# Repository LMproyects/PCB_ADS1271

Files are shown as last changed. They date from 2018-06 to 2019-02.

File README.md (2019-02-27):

# Diseño PCB de prueba para ADS1271

## Diseñadores
* Luciano Villarreal
* Marcos Postemsky

## Elección de pines

## Modo de operación
Vamos a trabajar con comunicación SPI, adquiriendo datos de forma continua (SYNC-PDWN='1')

## Pines a PinMod

**Para trabajar con SPI**
* **CLK:** reloj continuo que utiliza el ADC para muestreo y conversión.
* **SCLK:** Reloj utilizado para la comunicación SPI.
* **DOUT:** Datos de salida SPI.
* **DRDY:** Una vez que los datos válidos están listos, DRDY se pone en bajo.

### Pines ADS1271 fijos
* **SYNC/PDWN:** Se mantiene este valor en alto, para poder trabajar con adquisición de datos de manera continua. 

## Componentes necesarios
- 1 ADS1271: ADC de 24 bits Delta&Sigma con entrada y referencia diferencial.
- 6 pines con curva de 90º.
- 1 LM7805
- 1 Capacitor electrolítico 0.33 uF, 25V.
- 2 Capacitores electrolítico 0.1 uF
- 2 Capacitores electrolítico 10 uF
- 2 Capacitores cerámica 100 pF
- 1 Capacitores cerámica 1 nF
- 5 Resistencias de 50 Ohmios
- 1 Resistencia de 680 Ohmios
- 1 LM336z2.5 (se puede cambiar por zener de 2.5 v)
- 2 pines 2.54 mm
- 2 pines 2.54 mm

## Diseño del esquematico
Para el diseño del esquemático que será utilizado en el PCB de prueba, se tiene en cuenta el circuito recomendado por el fabricante Texas Instruments. A continuación, puede verse el circuito mencionado.

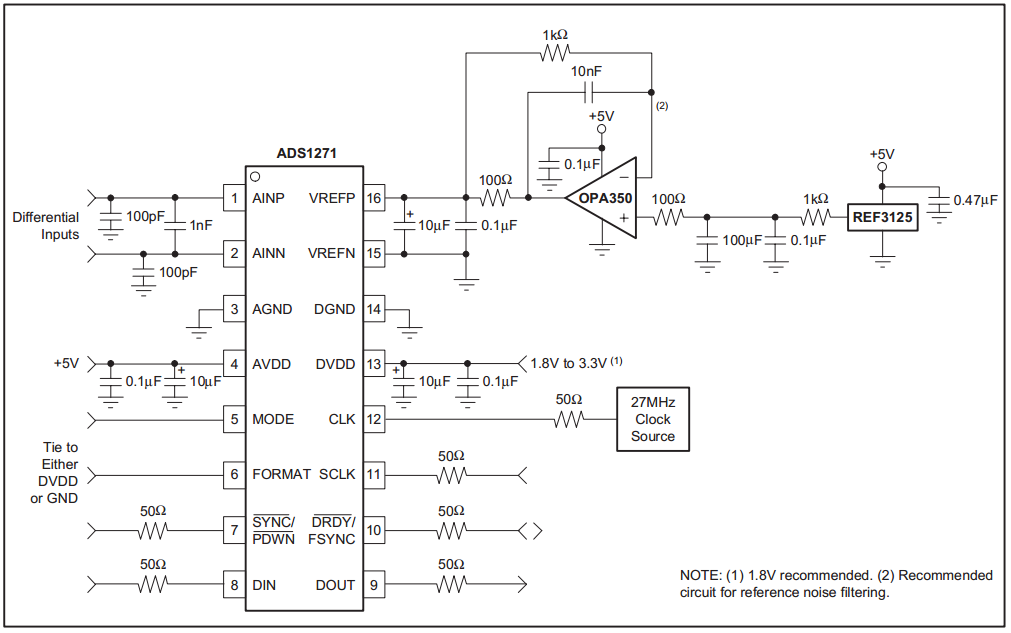
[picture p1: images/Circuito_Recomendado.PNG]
Imagen_circuito


## Circuitos de entrada

Para la entrada diferencial, el fabricante recomienda dos configuraciones dependiendo el modo en el que se quiera utilizar el ADC.

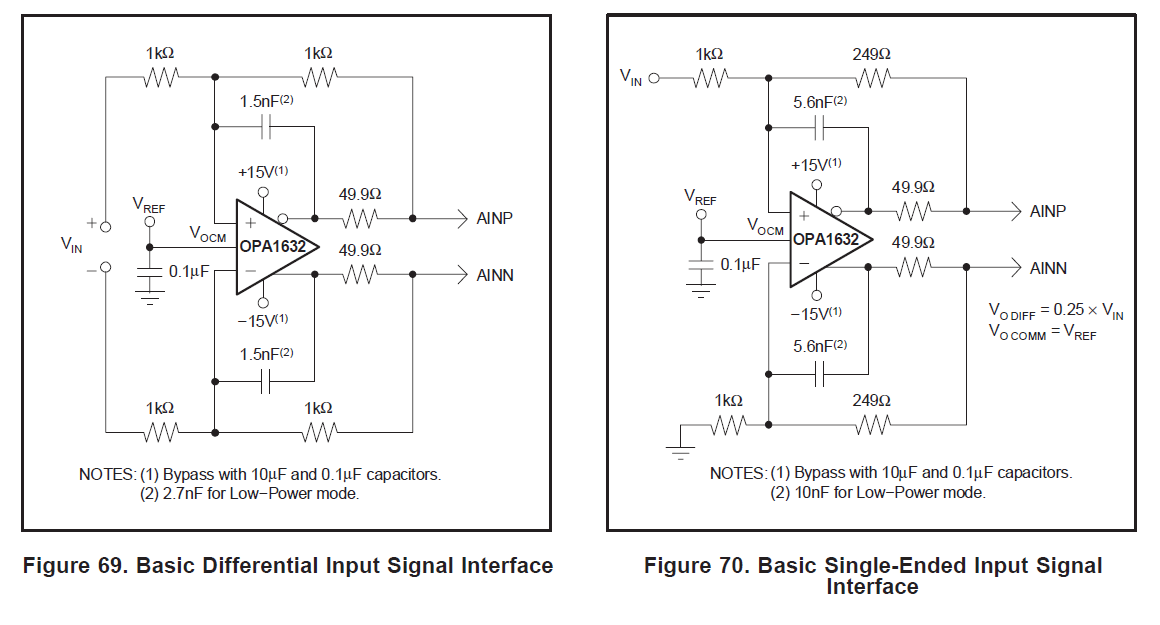
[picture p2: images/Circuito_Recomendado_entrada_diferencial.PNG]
Imagen_circuito_entrada_diferencial


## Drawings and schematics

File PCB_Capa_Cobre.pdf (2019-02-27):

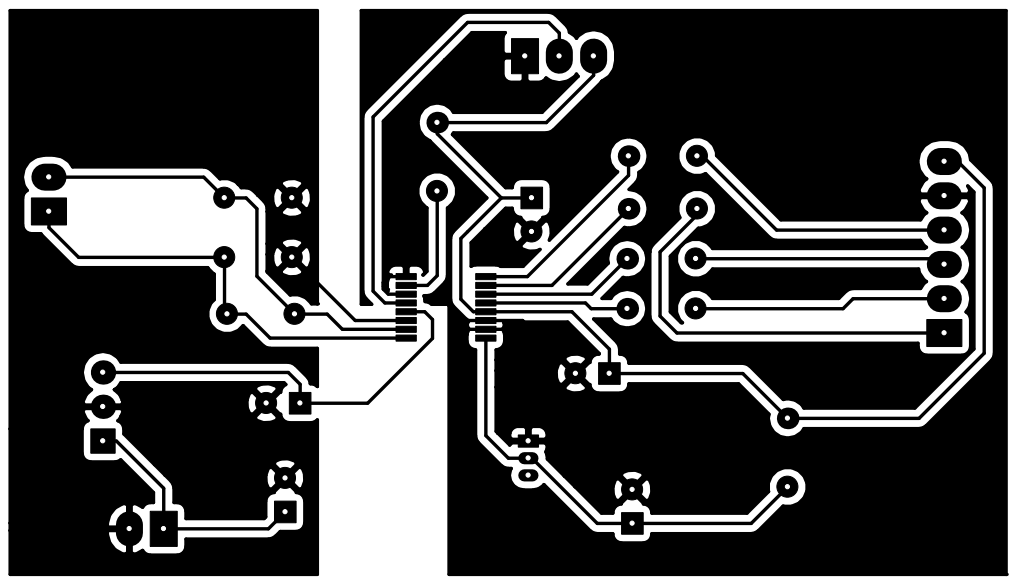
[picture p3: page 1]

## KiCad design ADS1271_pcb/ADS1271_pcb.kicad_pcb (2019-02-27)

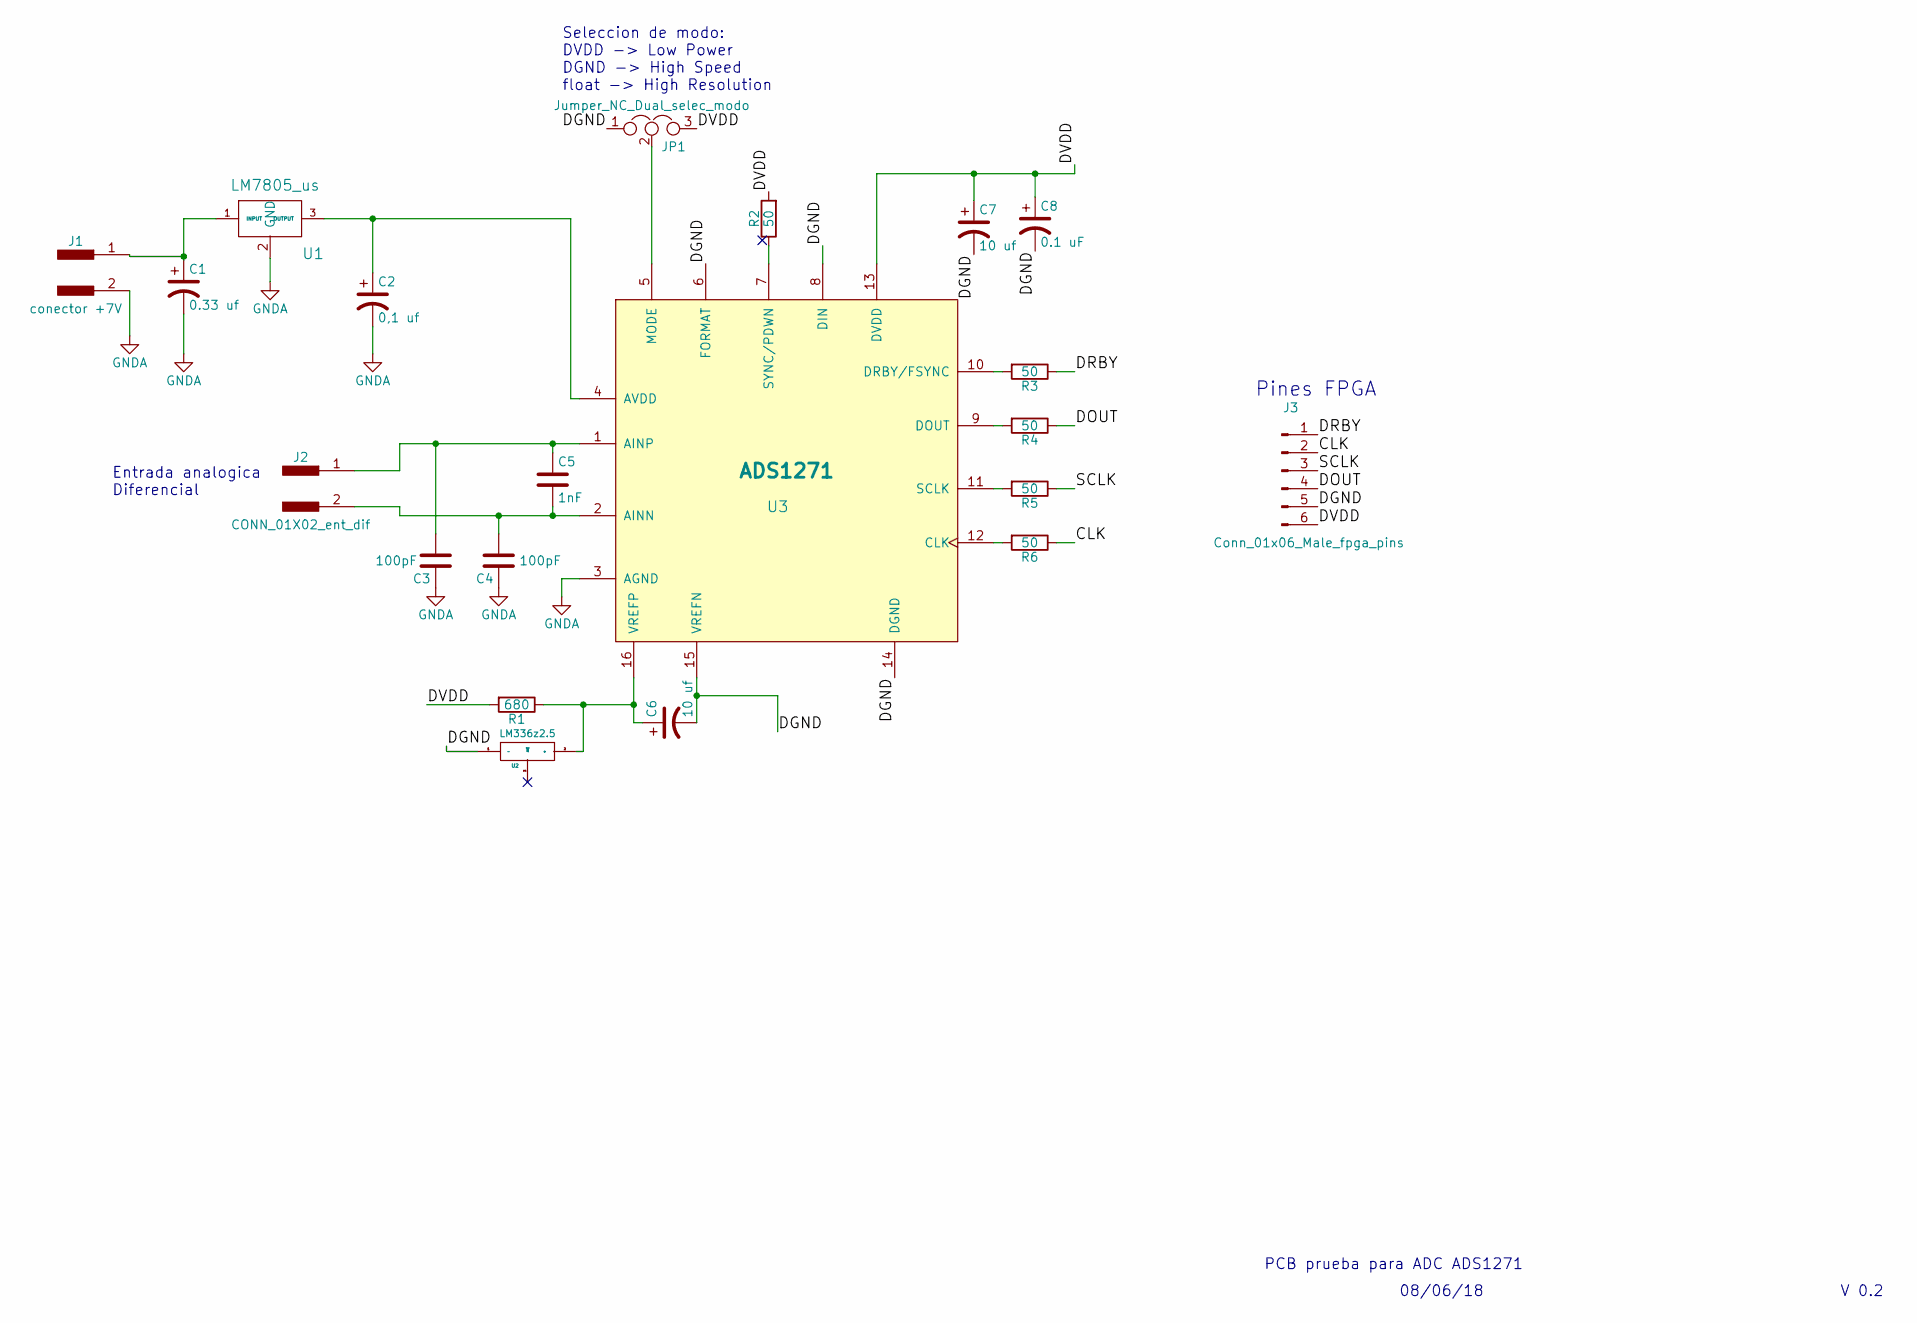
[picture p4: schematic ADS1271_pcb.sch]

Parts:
C1: 0.33 uf; CP_Radial_D5.0mm_P2.50mm
C2: 0,1 uf; CP_Radial_D5.0mm_P2.50mm
C3, C4: 100pF; C_Disc_D5.0mm_W2.5mm_P5.00mm
C5: 1nF; C_Disc_D5.0mm_W2.5mm_P5.00mm
C6, C7: 10 uf; CP_Radial_D5.0mm_P2.50mm
C8: 0.1 uF; CP_Radial_D5.0mm_P2.50mm
J1: conector +7V; Molex_SPOX-5267_22-03-5025_02x2.54mm_Straight
J2: CONN_01X02_ent_dif; Molex_SPOX-5267_22-03-5025_02x2.54mm_Straight
J3: Conn_01x06_Male_fpga_pins; Molex_SPOX-5267_22-03-5065_06x2.54mm_Straight
JP1: Jumper_NC_Dual_selec_modo; Molex_SPOX-5267_22-03-5035_03x2.54mm_Straight
R1: 680; R_Axial_DIN0207_L6.3mm_D2.5mm_P5.08mm_Vertical
R2, R3, R4, R5, R6: 50; R_Axial_DIN0207_L6.3mm_D2.5mm_P5.08mm_Vertical
U1: LM7805_us; TO-220-3_Vertical
U2: LM336z2.5; TO-92_Inline_Narrow_Oval
U3: ADS1271; TSSOP-16_4.4x5mm_Pitch0.65mm

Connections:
/CLK: J3.2, R6.1
/DGND: C6.2, C7.2, C8.2, J3.5, JP1.1, U2.1 (-), U3.6 (FORMAT), U3.8 (DIN), U3.14 (DGND), U3.15 (VREFN)
/DOUT: J3.4, R4.1
/DRBY: J3.1, R3.1
/DVDD: C7.1, C8.1, J3.6, JP1.3, R1.2, R2.2, U3.13 (DVDD)
/SCLK: J3.3, R5.1
GNDA: C1.2, C2.2, C3.1, C4.1, J1.2, U1.2 (GND), U3.3 (AGND)
unnamed: C1.1, J1.1, U1.1 (INPUT)
unnamed: C2.1, U1.3 (OUTPUT), U3.4 (AVDD)
unnamed: C3.2, C5.1, J2.1, U3.1 (AINP)
unnamed: C4.2, C5.2, J2.2, U3.2 (AINN)
unnamed: C6.1, R1.1, U2.2 (+), U3.16 (VREFP)
unnamed: JP1.2, U3.5 (MODE)
unnamed: R2.1, U3.7 (SYNC/PDWN)
unnamed: R3.2, U3.10 (DRBY/FSYNC)
unnamed: R4.2, U3.9 (DOUT)
unnamed: R5.2, U3.11 (SCLK)
unnamed: R6.2, U3.12 (CLK)

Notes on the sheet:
Pines FPGA
Entrada analogica Diferencial
Seleccion de modo: DVDD -> Low Power DGND -> High Speed float -> High Resolution
PCB prueba para ADC ADS1271
V 0.2
08/06/18

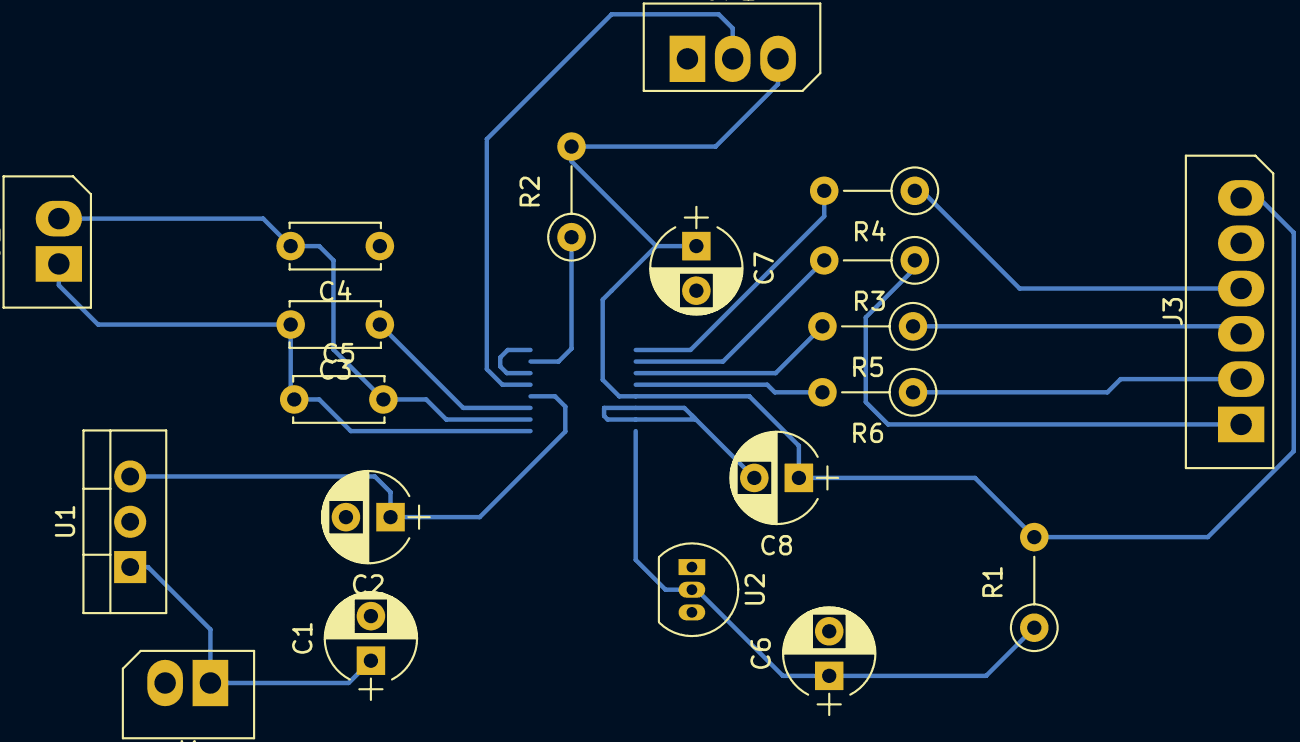
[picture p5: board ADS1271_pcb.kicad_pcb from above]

Board: 2 copper layers, 21 parts (1 on the bottom side), 18 nets.

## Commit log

2018-06-03 Agrego Readme comienzo pcb
2018-06-03 Creo proyecto kicad
    [ADS1271_pcb.kicad_pcb, ADS1271_pcb.sch]
2018-06-05 Terminé de generar componente ADS1271, faltan detalles finos
    [ADS1271_pcb.kicad_pcb, _saved_ADS1271_pcb.sch]
2018-06-05 cambios esquematico
    [ADS1271_pcb.sch, _saved_ADS1271_pcb.sch]
2018-06-05 Documentación en README
    [_saved_ADS1271_pcb.sch]
2018-06-05 Se sume imagen circuito
    [_saved_ADS1271_pcb.sch]
2018-06-05 Se agrega en el esquematico los labels y resistencias
    FALTA: Capacitores de bypass, baterías, y definir funciones del resto de los pines. @lvillarreal
    [ADS1271_pcb.sch, _saved_ADS1271_pcb.sch]
2018-06-05 Se cambia la conexión de la referencia
    [ADS1271_pcb.sch]
2018-06-08 Se completan los componentes basicos, expuestos en datasheet
    Faltaría ver si se coloca filtro de la referencia y filtro para la entrada diferencial.
    [ADS1271_pcb.sch]
2018-06-08 Cambios en los capacitores en líneas diferenciales analogicas
    [ADS1271_pcb.sch]
2018-07-07 Se listan los componentes
    [ADS1271_pcb.sch]
2019-02-23 cambio texto en readme
    Solo hago un pequeño cambio en la línea que presenta la figura del circuito recomendado.
2019-02-24 imagen de circuito de entrada
2019-02-27 PCB Terminado
    [ADS1271_pcb.kicad_pcb, ADS1271_pcb.sch]
2019-02-27 Se agrega pdf de la capa de cobre
2019-02-27 Actualizacion de componentes
2019-02-27 Se cambian dos capacitores de ceramica por dos electroliticos, en entrada dvdd (pin 13)
    [ADS1271_pcb.kicad_pcb, ADS1271_pcb.sch]
